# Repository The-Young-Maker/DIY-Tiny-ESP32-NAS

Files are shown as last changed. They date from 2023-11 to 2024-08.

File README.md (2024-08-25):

# DIY-Tiny-ESP32-NAS
A DIY Tiny ESP32 NAS with support for 3 SD cards and a web interface!
 
  To make this project, I suggest you check ou the instructable I made : https://www.instructables.com/Diy-Small-But-Powerful-ESP32-NAS/
  
  I need your help for this project!!  If you want to help me to make this project better, please email me at loicdaigle31@gmail.com .

Note: While this project is capable of serving a personalized homepage, it has certain limitations in handling a large number of simultaneous visitors. If you're keen on establishing a web server designed to accommodate a broader audience, I encourage you to explore my dedicated tutorial on this subject, accessible on my website: [Creating Your Own Apache Server](https://theyoungmaker.dev/pages/tutorials/Make_a_server/).

## To Compile the code
You need to take all the files from the "code" folder and put them in a folder called "web-server" then, you should be able to compile the code.

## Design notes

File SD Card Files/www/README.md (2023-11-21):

 

# TinyNAS

A ESP32 powered web server with NAS functionality

## Features

- Basic Web Server

- Directory View 

- Cookie based login system

- File Manager
  
  - File Upload / Download (with multiple-file zip download support)
  
  - File Open, Cut and Copy
  
  - Support UTF-8 filename (32 bit length only, filename length depends on variable bytes used per char)

- File Searching Tool
  
  - Much slower than Google Search (Is this even a feature?)

- System Information
  
  - SD storage info
  - WiFi info

- WebApps
  
  - Music Player
  - Photo Viewier
  - Video Player
  - Markdown Editor
  - Notepad (Modified version of ACE Editor)

## Usage

### Hosting

1. Format your micro SD card as FAT (Recommend using [SD Card Formatter](https://www.sdcard.org/downloads/formatter/))
2. Download and put everything under sd_card folder in this repo into your micro SD card
3. Edit the files under /cfg/ to setup WiFi credentials (wifi.txt), management passwords (admin.txt) and optionally mDNS domain name (mdns.txt)
4. Insert your SD card into the TinyNAS SD card slot
5. Power on your TinyNAS by inserting it into your computer USB port (for debug / flash mode) or phone charger with USB A port.
6. Access your TinyNAS using the device IP address (http://192.168.0.100/) or mDNS name (e.g. http://TinyNAS.local)

#### Using your domain with TinyNAS

mDNS are local only domain names. If you want your viewer to be able to access your website from the public internet via your domain or your home public ip address, you will need to purchase a domain name, setup your DNS and / or your NAT router's port forward rules. 

### Build from Source

The following libraries are required for building the TinyNAS backend code (firmware to be used in ESP8266) using Arduino IDE. You can find the source code for the backend bare metal web-server in the ```/web-server``` folder.

#### Board Settings

Here are the recommended settings for best performance.

- Board: Wemos D1 R2 & Mini
  
  * CPU clockspeed: 160Mhz
  
  * IwIP Varient: v2 Higher Bandwidth

## Screenshots

#### Basic Web Servers

The TinyNAS provide basic web server functions like a fresh install Apache



▲ Homepage template



▲ Web server for HTML files



▲ Directory listing

#### Admin / Management Functions

TinyNAS contains basic functions for single admin environment. All file operations can only be performed by the only admin user in this system.



▲ Login / User System (based on Cookie not Basic Auth)



▲File Manager (Support upload, (multi-zip) download, copy, cut, paste, rename and new folder / files)



▲ Basic Search Engine (for local files)



▲ System Statistics

#### Multimedia

There are also limited multimedia streaming functionality on the TinyNAS.



▲ Basic Music Player



▲ Video Player (really small webm / mp4 files only)



▲ Photo Viewer

#### Other Utilities

TinyNAS also got other text editing utilities. If you are using markdown as notes or you want to update your website remotely, you can use the markdown editor or the notepadA editor. 



▲ Markdown Editor (Powered by SimpleMDE project)



▲ NotepadA Code Editor (Powered by ace editor, support multi-tabs)

## Limitations

As you might have notice by now this system is hosted on a 1 USD MCU (ESP32), even if web server is written in bare metal, it still have the following limitations

- Filename length (hardcoded to 32 bits per filename, might be shorter for UTF-8 as it use variable byte structure, but technically this is not the system limit)

- File size limit (recommend) <= 5MB, any file size larger than 5MB that is not stream-able (e.g. mp4) is not meaningful. Stream-able files can be larger than this size (e.g. webm) with acceptable playback speed.

- Slow Upload / Download speed (2 - 4Mbps), Very slow concurrent R/W speed (200 - 210 Kbps)

- Single admin session (cookie), due to limit in runtime memory (i.e. If you try to login from 2nd browser, the first browser will automatically logged out)

## License
Hardware Design (PCB files): CC BY-NC-SA

Backend Code (Arduino): MIT License

Front-end Code (html files): AGPL

*(I strongly recommend anyone with ability to write a better UI than my system :D)*

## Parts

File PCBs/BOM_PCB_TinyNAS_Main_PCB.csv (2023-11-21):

ID | Name | Designator | Footprint | Quantity | Manufacturer Part | Manufacturer | Supplier | Supplier Part | Price | link
1 | 1uF | C1,C2,C3 | C0402 | 3 | CL05A105KP5NNNC | SAMSUNG(三星) | LCSC | C14445 | 0.002 | https://lcsc.com/eda_search?q=C14445&%26type=1&ref=editor
2 | KH-FG0.5-H2.0-11PIN | FPC1 | FPC-SMD_KH-FG0.5-H2.0-11PIN | 1 | KH-FG0.5-H2.0-11PIN | kinghelm(金航标) | LCSC | C2932710 | 0.088 | https://lcsc.com/eda_search?q=C2932710&%26type=1&ref=editor
3 | 1kΩ | R1 | R0402 | 1 | 0402WGF1001TCE | UNI-ROYAL(厚声) | LCSC | C11702 | 0.001 | https://lcsc.com/eda_search?q=C11702&%26type=1&ref=editor
4 | 5.1kΩ | R2,R3 | R0402 | 2 | 0402WGF5101TCE | UNI-ROYAL(厚声) | LCSC | C25905 | 0.001 | https://lcsc.com/eda_search?q=C25905&%26type=1&ref=editor
5 | CP2102N-A02-GQFN24R | U2 | QFN-24_L4.0-W4.0-P0.50-TL-EP2.6 | 1 | CP2102N-A02-GQFN24R | SILICON LABS(芯科) | LCSC | C969151 | 1.96 | https://lcsc.com/eda_search?q=C969151&%26type=1&ref=editor
6 | GT-USB-7010ASV | U3 | USB-C-SMD_G-SWITCH_GT-USB-7010ASV | 1 | GT-USB-7010ASV | G-Switch(品赞) | LCSC | C2988369 | 0.079 | https://lcsc.com/eda_search?q=C2988369&%26type=1&ref=editor
7 | MUN5214DW1T1G | Q1 | SOT-363_L2.0-W1.3-P0.65-LS2.1-TL | 1 | MUN5214DW1T1G | onsemi(安森美) | LCSC | C94403 | 0.05 | https://lcsc.com/eda_search?q=C94403&%26type=1&ref=editor
8 | 4.7uF | C4,C5 | C0402 | 2 | CL05A475MQ5NRNC | SAMSUNG(三星) | LCSC | C307423 | 0.003 | https://lcsc.com/eda_search?q=C307423&%26type=1&ref=editor
9 | AMS1117-3.3 | U1 | SOT-223-3_L6.5-W3.4-P2.30-LS7.0-BR | 1 | AMS1117-3.3 | AMS | LCSC | C6186 | 0.141 | https://lcsc.com/eda_search?q=C6186&%26type=1&ref=editor
10 | ESP32-WROVER-B(8MB) | U5 | WIFIM-SMD_39P-L31.4-W18.0-P1.27 | 1 | ESP32-WROVER-E-N16R8 | ESPRESSIF(乐鑫) | LCSC | C529589 |  | https://lcsc.com/eda_search?q=C529590&%26type=1&ref=editor

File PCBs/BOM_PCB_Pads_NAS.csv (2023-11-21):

ID | Name | Designator | Footprint | Quantity | Manufacturer Part | Manufacturer | Supplier | Supplier Part | Price | link
1 | ANT-SMD_KH-3051515-TP | U4,U5,U6,U7,U8,U9,U10,U13,U14,U15,U16,U17,U18,U19,U22,U23,U24,U25,U26,U27,U28 | ANT-SMD_KH-3051515-TP | 21 | KH-3051515-TP | kinghelm(金航标) | LCSC | C2837575 | 0.034 | https://atta.szlcsc.com/upload/public/pdf/source/20210608/C2837575_CD48976F4C8B5049C0CCE20B9C63B7A8.pdf
2 | FPC-SMD_KH-FG0.5-H2.0-11PIN | U1 | FPC-SMD_KH-FG0.5-H2.0-11PIN | 1 | KH-FG0.5-H2.0-11PIN | kinghelm(金航标) | LCSC | C2932710 | 0.088 | https://lcsc.com/eda_search?q=C2932710&%26type=1&ref=editor

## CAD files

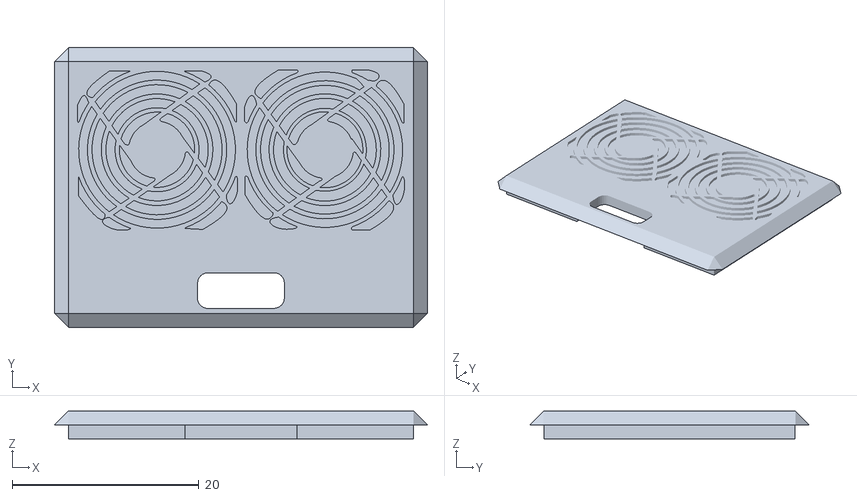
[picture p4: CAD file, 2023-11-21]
3D Files/DIY TinyNAS Backplate.stl
40.0 x 30.0 x 3.00

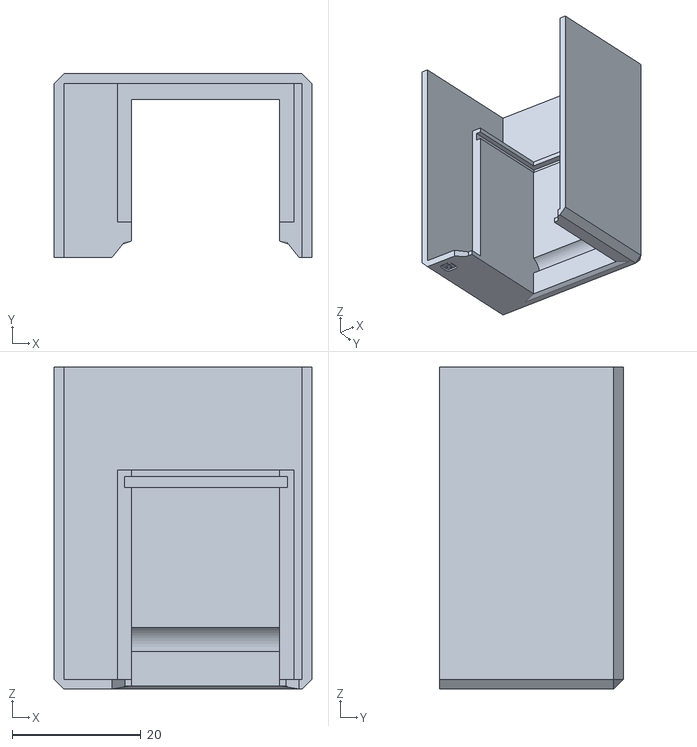
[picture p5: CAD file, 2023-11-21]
3D Files/DIY TinyNAS Body NO Logo.stl
40.0 x 28.5 x 50.0

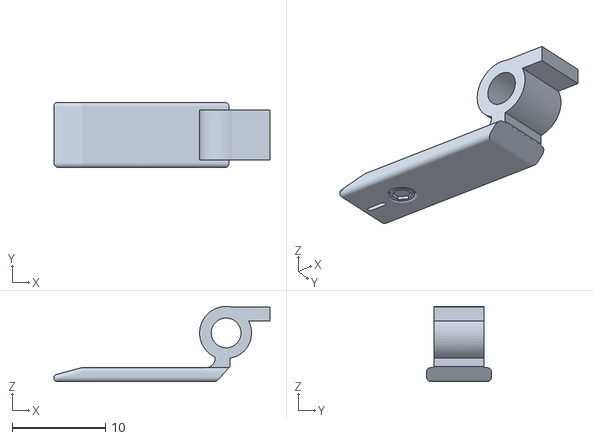
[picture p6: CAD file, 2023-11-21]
3D Files/SD Enclosure Lever.stl
23.2 x 7.00 x 8.07

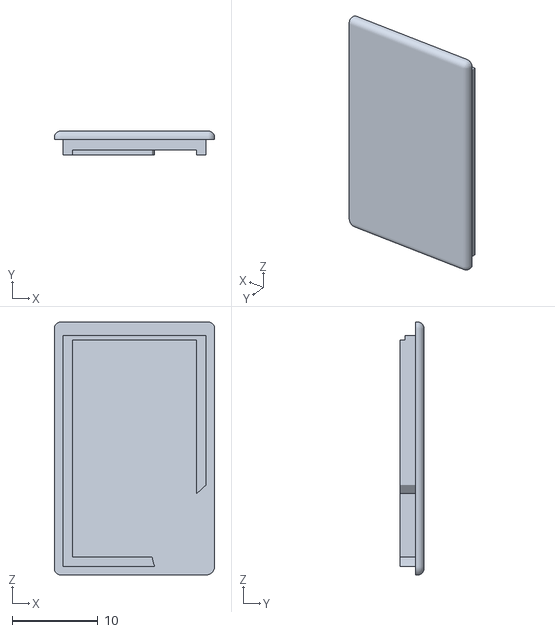
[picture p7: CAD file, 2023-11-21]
3D Files/SD Enclosure Lid.stl
18.7 x 2.80 x 29.5

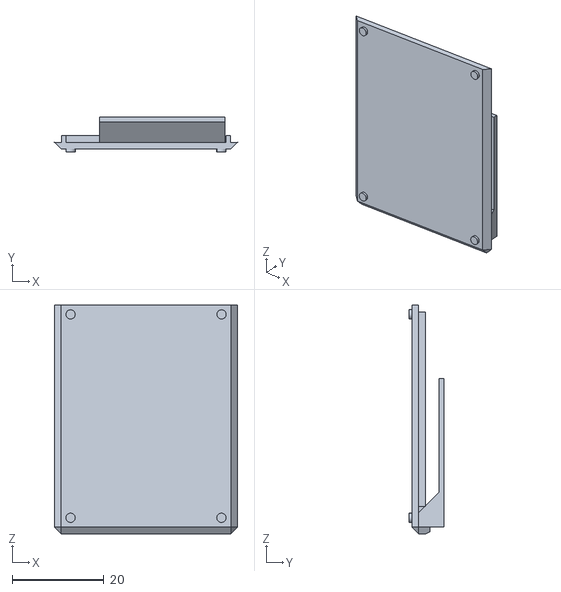
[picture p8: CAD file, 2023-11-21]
3D Files/DIY TinyNAS Bottom.stl
40.0 x 7.60 x 50.0

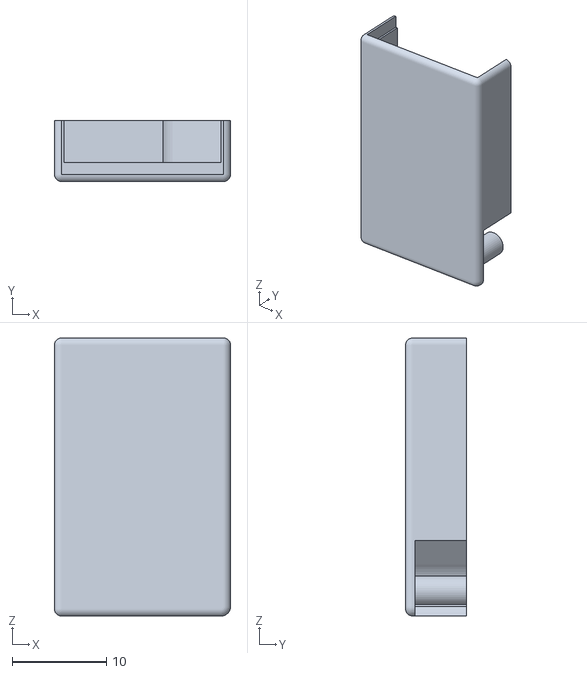
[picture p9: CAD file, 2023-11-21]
3D Files/SD Enclosure Body.stl
18.7 x 6.47 x 29.5

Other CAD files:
3D Files/DIY TinyNAS Body With Logo.stl
3D Files/DIY TinyNAS Backplate.f3d
3D Files/DIY TinyNAS Body NO Logo.f3d
3D Files/DIY TinyNAS Body With Logo.f3d
3D Files/DIY TinyNAS Bottom.f3d
3D Files/DIY TinyNAS Complete.f3d
3D Files/SD Enclosure Body.f3d
3D Files/SD Enclosure Lever.f3d
3D Files/SD Enclosure Lid.f3d
3D Files/SD enclosure Complete.f3d

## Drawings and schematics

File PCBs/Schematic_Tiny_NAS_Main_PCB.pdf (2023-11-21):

CP2102N | USB-C

## ESP32 WROVER

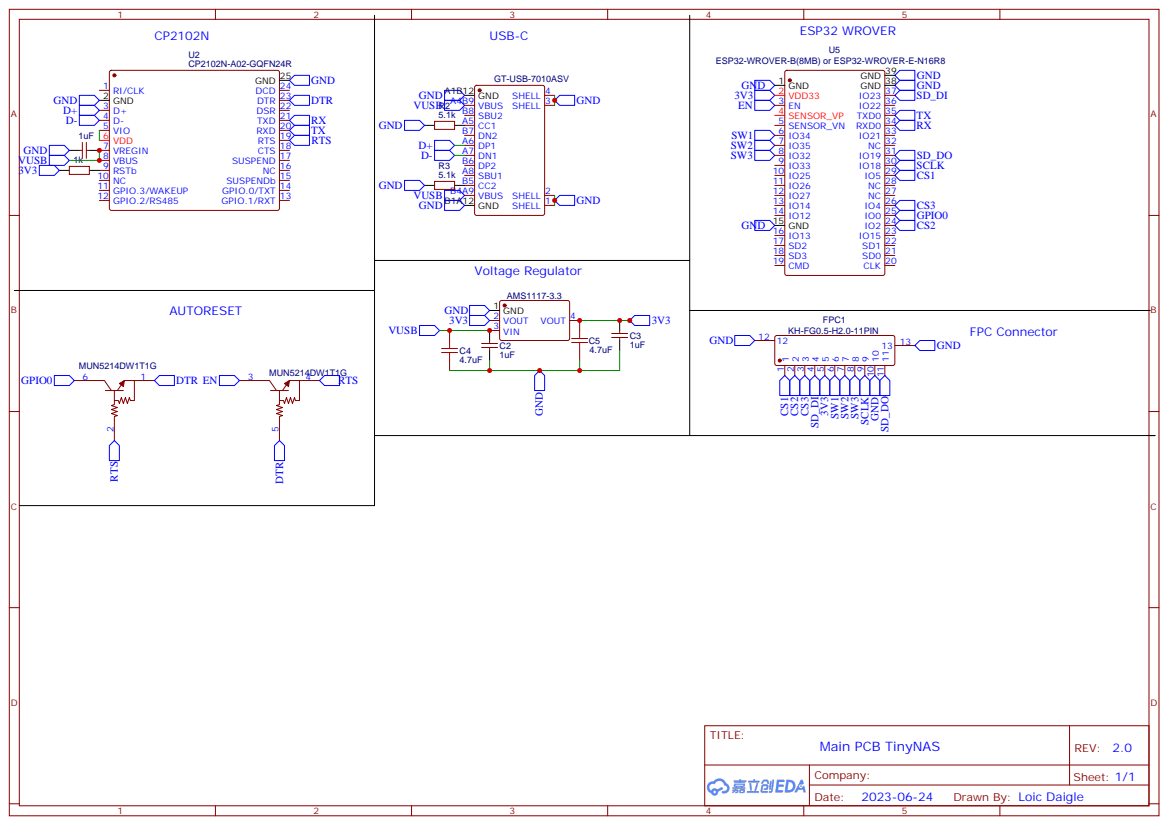
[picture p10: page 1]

Drawn By: Loic Daigle

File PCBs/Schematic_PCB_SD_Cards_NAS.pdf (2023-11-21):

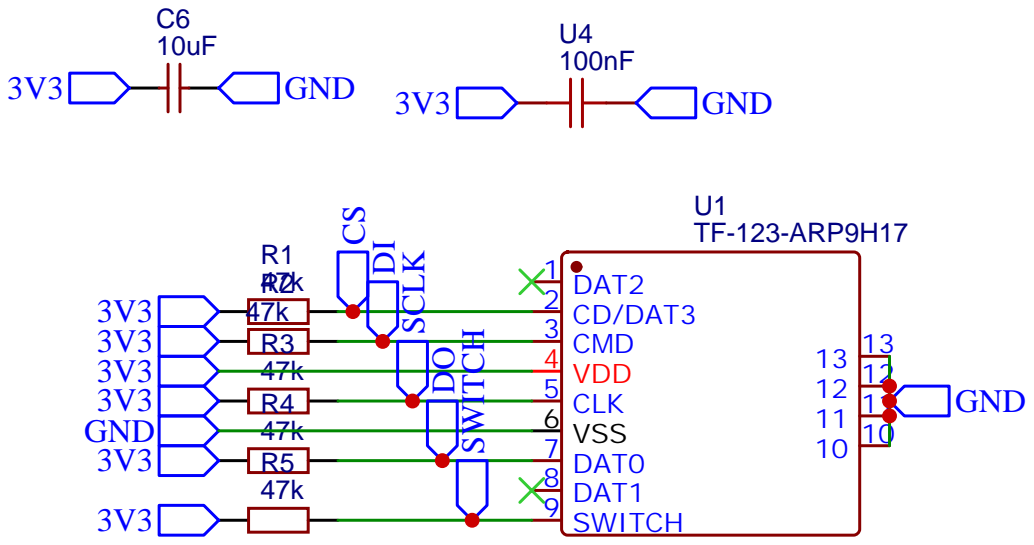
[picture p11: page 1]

Drawn By: Loic Daigle

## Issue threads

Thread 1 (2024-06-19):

How to use Li ion 3.7v battery

hoathienvu8x, 2024-06-19:
Hi The Young Maker

Thanks for shared this project. I have a little issues how to use Li ion 3.7v battery

The-Young-Maker, 2024-06-19:
Hi,

A lithium battery might not provide enough power for this project because both the SD cards and the ESP32 draw significant current. I encountered this issue during my design phase since the 5V to 3.3V converter wasn’t supplying sufficient current.

If you manage to find a battery with a high enough current output, you can connect it to the 5V input of the PCB. The built-in regulator will then convert it to 3.3V as needed. However, be aware that the battery, depending on its capacity, may not last very long under such a load. Additionally, there is no built-in battery charger circuit, so you would need to add your own.

I hope this helps!

hoathienvu8x, 2024-06-19:
Hi The Young Maker

Thanks for suggestion ideas, i think Li-ion battery is backup when power is disconnected, but I'm not familiar with electronics to convert voltage.

I see a typical Nokia phone using a 3.7 Li-ion battery but I don't understand how to implement this circuit

The-Young-Maker, 2024-06-19:
As I said, if you have a sufficiently powerful 3.7V lithium battery, you will only need to connect it to the 5V input (5V from USB), but be careful not to connect the battery 3 .7 V if USB is plugged in as this is probably the case. will break your battery. Additionally, to implement a circuit where the battery only powers the circuit when the USB port is unplugged, it would need to be added to the design. I might create a v2 to add this functionality, but I can't promise anything since I’m currently working on a big project.

Closed 2024-06-20.

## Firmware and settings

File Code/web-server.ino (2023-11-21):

//WiFi library
#include <WiFi.h>
//SD cards library
#include <SPI.h>
#include <SD.h>
#include <FS.h>

//Web server library

#include <ESPAsyncWebServer.h>
#include <ArduinoJson.h>

//Discovery related library
#include <ESPmDNS.h>
#include <NTPClient.h>
#include <WiFiUdp.h>

/* Hardware Configurations */
#define CS_PIN 5 // 5, 2, 4

/* Software Global Variables */
AsyncWebServer server(80);
String adminUsername = "";
String adminPassword = "";
String mdnsName = "webstick";
String authSession = "";

/* Time Keeping */
WiFiUDP ntpUDP;
NTPClient timeClient(ntpUDP, "pool.ntp.org");

/* Debug variables */

/* Function definations */
String loadWiFiInfoFromSD();


void setup() {
  // Setup Debug Serial Port
  Serial.begin(115200);
  
  //Try Initialize SD card (blocking)
  while (!SD.begin(CS_PIN,SPI,4000000U,"/sd",15U,false)){
    Serial.println("SD card initialization failed. Retrying in 3 seconds...");
    delay(3000);
  }
  Serial.println("SD card initialized");
  // Serial.println("\n\nStorage Info:");
  // Serial.println("----------------------");
  // getSDCardTotalSpace();
  // getSDCardUsedSpace();
  // Serial.println("----------------------");
  // Serial.println();

  //Connect to wifi based on settings (cfg/wifi.txt)
  initWiFiConn();

  //Load admin credentials from SD card (cfg/admin.txt)
  initAdminCredentials();
  
  //Start mDNS service
  initmDNSName();
  if (!MDNS.begin(mdnsName)){
      Serial.println("mDNS Error. Skipping.");
  }else{
      Serial.println("mDNS started. Connect to your webstick using http://" + mdnsName + ".local");
      MDNS.addService("http", "tcp", 80);
  }

  //Start NTP time client
  timeClient.begin();
  Serial.print("Requesting time from NTP (unix timestamp): ");
  timeClient.update();
  Serial.println(getTime());

  //Initialize database
  DBInit();

  //Resume login session if any
  initLoginSessionKey();
  
  // Start listening to HTTP Requests
  initWebServer();
}
  

void loop(){
  timeClient.update();
  delay(10);
}

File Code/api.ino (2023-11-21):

/*

    API.ino

    This script handle API requests
    functions.
*/

/* Utilities Functions */
String GetPara(AsyncWebServerRequest *request, String key) {
  if (request->hasParam(key)) {
    return request->getParam(key)->value();
  }
  return "";
}

void SendErrorResp(AsyncWebServerRequest *r, String errorMessage) {
  //Parse the error message into json
  StaticJsonDocument<200> jsonDocument;
  JsonObject root = jsonDocument.to<JsonObject>();
  root["error"] = errorMessage;
  String jsonString;
  serializeJson(root, jsonString);

  //Send it out with request handler
  r->send(200, "application/json", jsonString);
}

void SendJsonResp(AsyncWebServerRequest *r, String jsonString) {
  r->send(200, "application/json", jsonString);
}

void SendOK(AsyncWebServerRequest *r) {
  r->send(200, "application/json", "\"ok\"");
}

//Handle auth check if the request has been authed.
//Return false if user is not authed
bool HandleAuth(AsyncWebServerRequest *request) {
  //Handle for API calls authentication validate
  if (!IsUserAuthed(request)) {
    //user not logged in
    request->send(401, "text/html", "401 - Unauthorized");
    return false;
  }

  return true;
}

/*

    Handler Functions

    These are API endpoints handler
    which handle special API call
    for backend operations

*/

/* Authentications */
//Check if the user has logged in
void HandleCheckAuth(AsyncWebServerRequest *r) {
  if (IsUserAuthed(r)) {
    SendJsonResp(r, "true");
  } else {
    SendJsonResp(r, "false");
  }
}

//Handle login request
void HandleLogin(AsyncWebServerRequest *r) {
  String username = GetPara(r, "username");
  String password = GetPara(r, "password");
  if (adminUsername == "") {
    SendErrorResp(r, "admin account not enabled");
    return;
  }
  if (username.equals(adminUsername) && password.equals(adminPassword)) {
    //Username and password correct. Set a cookie for this login.
    //Generate a unique cookie for this login session
    String cookieId = GeneratedRandomHex();
    Serial.print("Generating new cookie ID ");
    Serial.println(cookieId);

    String expireUTC = getUTCTimeString(getTime() + 604800);
    Serial.print("Generating expire UTC timestamp ");
    Serial.println(expireUTC);

    AsyncWebServerResponse *response = r->beginResponse(200, "application/json", "\"ok\"");
    response->addHeader("Server", mdnsName);
    response->addHeader("Cache-Control", "no-cache");
    response->addHeader("Set-Cookie", "web-auth=" + cookieId + "; Path=/; Expires=" + expireUTC + "; Max-Age=604800");

    //Save the cookie id
    DBWrite("auth", "cookie", cookieId);
    authSession = cookieId;

    //Return login succ
    r->send(response);

    Serial.println(username + " logged in");
  } else {
    SendErrorResp(r, "invalid username or password");
    return;
  }
  SendOK(r);
}

//Handle logout request, or you can logout with
//just front-end by going to log:out@{ip_addr}/api/auth/logout
void HandleLogout(AsyncWebServerRequest *r) {
  if (!IsUserAuthed(r)) {
    SendErrorResp(r, "not logged in");
    return;
  }

  //Remove the cookie on client side
  AsyncWebServerResponse *response = r->beginResponse(200, "application/json", "\"ok\"");
  response->addHeader("Server", mdnsName);
  response->addHeader("Cache-Control", "no-cache");
  response->addHeader("Set-Cookie", "web-auth=deleted; path=/; expires=Thu, 01 Jan 1970 00:00:00 GMT");
  r->send(response);

  //Delete the server side cookie
  DBRemove("auth", "cookie");
  authSession = "";
}

/* File System Functions */
//HandleListDir handle the listing of directory under /www/
void HandleListDir(AsyncWebServerRequest *r) {
  if (!HandleAuth(r)) {
    return;
  }

  //Get the folder path to be listed
  //As ESP8266 dont have enough memory for proper struct to json conv, we are hacking a json string out of a single for-loop
  String jsonString = "[";
  String folderPath = GetPara(r, "dir");
  folderPath = "/www" + folderPath;
  if (SD.exists(folderPath)) {
    File root = SD.open(folderPath);
    bool firstObject = true;
    if (root) {
      while (true) {
        File entry = root.openNextFile();
        if (!entry) {
          // No more files
          break;
        } else {
          //There are more lines. Add a , to the end of the previous json object
          if (!firstObject) {
            jsonString = jsonString + ",";
          } else {
            firstObject = false;
          }
        }

        String isDirString = "true";
        if (!entry.isDirectory()) {
          isDirString = "false";
        }
        jsonString = jsonString + "{\"Filename\":\"" + entry.name() + "\",\"Filesize\":" + String(entry.size()) + ",\"IsDir\":" + isDirString + "}";
        entry.close();
      }
      root.close();

      jsonString += "]";
      SendJsonResp(r, jsonString);
    } else {
      SendErrorResp(r, "path read failed");
    }
  } else {
    SendErrorResp(r, "path not found");
  }
  Serial.println(folderPath);
}

//Handle file rename on SD card
void HandleFileRename(AsyncWebServerRequest *r) {
  if (!HandleAuth(r)) {
    return;
  }
  String srcFile = GetPara(r, "src");
  String destFile = GetPara(r, "dest");
  srcFile.trim();
  destFile.trim();
  srcFile = "/www/" + srcFile;
  destFile = "/www/" + destFile;
  if (!SD.exists(srcFile)) {
    SendErrorResp(r, "source file not exists");
    return;
  }

  if (SD.exists(destFile)) {
    SendErrorResp(r, "destination file already exists");
    return;
  }

  SD.rename(srcFile, destFile);
  SendOK(r);
}


//Handle file delete on SD card
void HandleFileDel(AsyncWebServerRequest *r) {
  if (!HandleAuth(r)) {
    return;
  }
  String targetFile = GetPara(r, "target");
  targetFile.trim();
  if (targetFile.equals("/")) {
    //Do not allow remove the whole root folder
    SendErrorResp(r, "you cannot remove the root folder");
    return;
  }
  targetFile = "/www" + targetFile;
  if (!SD.exists(targetFile)) {
    SendErrorResp(r, "target file not exists");
    return;
  }



  if (!SD.remove(targetFile)) {
    if (IsDir(targetFile)) {

      //Try remove dir
      if (!SD.rmdir(targetFile)) {
        //The folder might contain stuffs. Do recursive delete
        Serial.println("rmdir failed. Trying recursive delete");
        if (recursiveDirRemove(targetFile)) {
          SendOK(r);
        } else {
          SendErrorResp(r, "folder delete failed");
        }

      } else {
        SendOK(r);
      }
    } else {
      SendErrorResp(r, "file delete failed");
    }
    return;
  }

  SendOK(r);
}
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
